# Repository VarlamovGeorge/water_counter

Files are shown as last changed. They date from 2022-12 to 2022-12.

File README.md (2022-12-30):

# IoT-проект для работы с домашними счетчиками воды
Репозиторий представляет собой решение для организации сбора и хранения статистики потребления воды в квартире.

Больше не нужно переживать о том, что вы забудете передать показания воды вовремя. Не нужно каждый месяц лезть в под раковину или открывать технический лючок в санузле. Telgram бот сам напомнит про передачу показаний - пришлет вам актуальное значение счетчиков и даст ссылку на mos.ru. А если захочется провести анализ расхода воды за прошлые периоды - вы сможете сделать это с помощью интерактивных дашбордов прямо в браузере.

<p align="left">
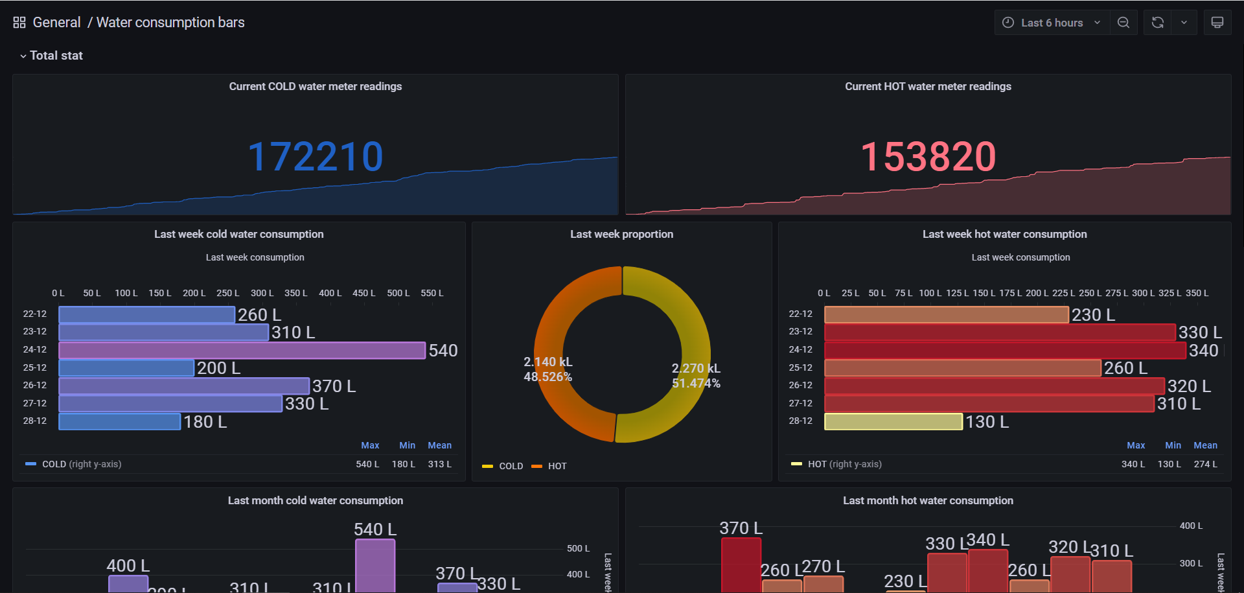
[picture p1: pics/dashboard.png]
  
</p>

## Возможности:
Проект позволяет реализовать следующие возможности для взаимодействия со счетчиками потребления воды:
- сохранение показаний счетчиков в локальную базу данных;
- отображение дашбордов со статистикой потребления;
- взаимодействие с системой через Telegram-бота.

### Telegram-бот
Реализованы следующие возможности бота:
1. Напоминание о необходимости отправки показаний  
Приходит в заранее заданные числа месяца и содержит текущие показания счетчиков, а также ссылку на сайт для передачи показаний (по умолчанию - на портал госуслуг города Москвы mos.ru). У пользователя есть возможность подтвердить отправку (напоминание будет отложено дл следующего месяца) или опровергнуть ее (напоминание будет повторено на следующий день).

2. Получение текущих показаний счетчиков
3. Получение дельты потребления по всем счетчикам за последние 7 и 30 календарных дней

## Требуемое оборудование
1. Raspberry Pi или любой другой компьютер, поддерживающий Python 3, установку Grafana, Mosquitto, Node-RED и SQLite;
1. IoT-микроконтроллер (Wemos D1 mini или любой аналогичный микроконтроллер на основе ESP8266) - по числу счетчиков в квартире;
1. Набор электронных компонент: тактовая кнопка, коннекторы и Breadboard для их подлючения к микроконтроллеру;
1. Водяные счетчики с проводом для подключения к считывающим устройствам.

## Архитектура

<p align="left">
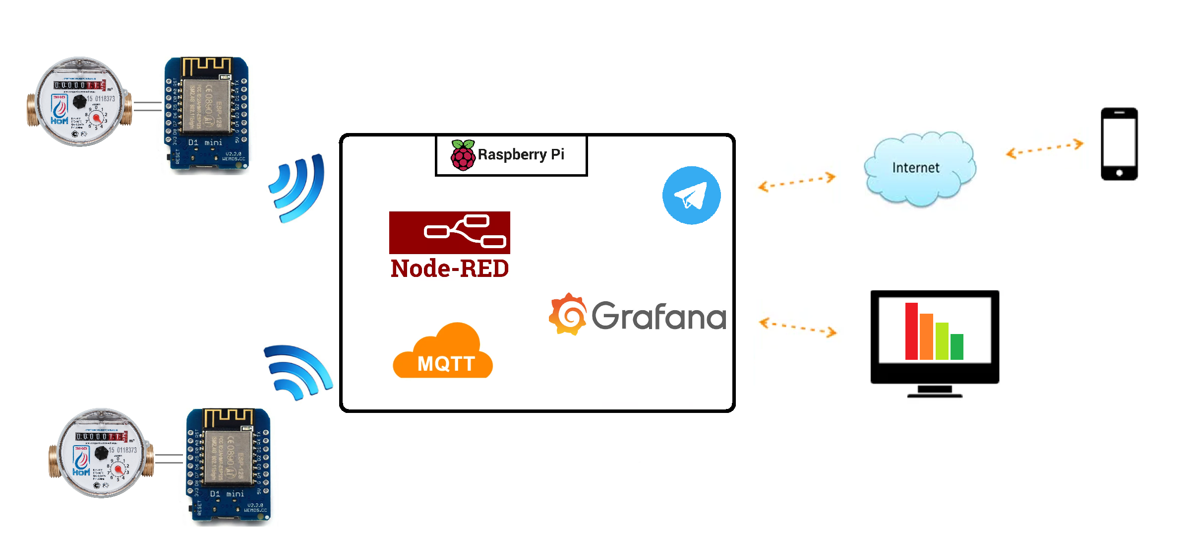
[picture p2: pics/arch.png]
  
</p>
Рядом с каждым счетчиком воды устанавливается IoT-микроконтроллер с WiFi (например - Wemos D1 mini), который подключается к счетчику его родными проводами, после чего с заданной периодичностью рассылает данные о текущих значениях потребления по протоколу MQTT.

Программа микроконтроллера позволяет работать в двух режимах:
1. Основной  
Устройство переходит в режим глубокого сна, и просыпается только для:
- опроса счетчика (по умолчанию - раз в 4-5 секунд)  
При каждом замыкании контактов счетчика текущее показание инкрементируется на 10 литров;
- отправки данных на сервер (по умолчанию - раз в 30 минут)  
Для этого микроконтроллер стартует в качестве клиента, подключающегося к домашней точке доступа Wi-Fi (2,4 ГГц) и рассылающего сообщения в соответствующий MQTT-топик.

2. Настроечный  
Микроконтроллер функционирует в качестве точки доступа Wi-Fi (2,4 ГГц), после подключения к которой пользователю становится доступна web-страница настроек.

В периметре квартиры (дома) поднимается Linux-сервер, с установленной БД и MQTT-брокером сообщений. Сервер подписывается на MQTT-сообщения в топиках для соответствующих счетчиков (для удобства настройки используется Node-RED) и складывает получаемые показания в локальную БД. На том же сервере развернута Grafana для визуализации статистики, а также работает Python-скрипт, отвечающий за Telegram-бота.

### Схема подключения Wemos D1 mini:
<p align="left">
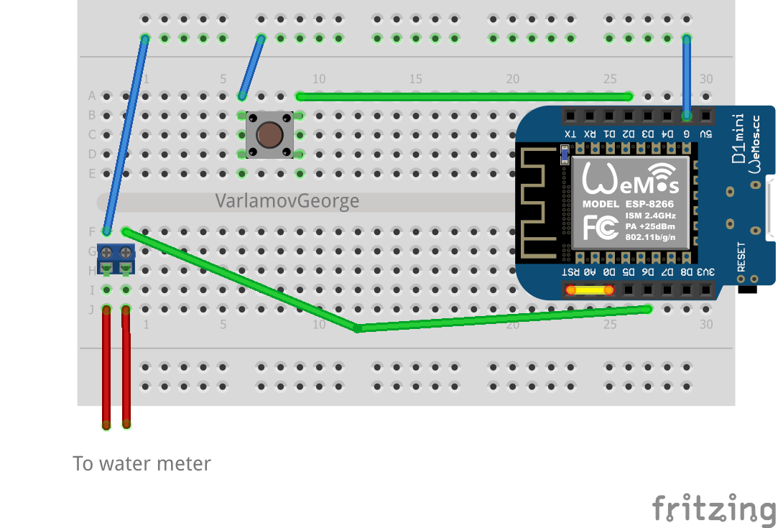
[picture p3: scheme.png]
  
</p>

### Счетчики
Допускается использование счетчиков с количеством разрядов не более 8 (обычно самый младший разряд отвечает за единицы литров, но это не является обязательным условием). Подключать счетчики к системе необходимо проводами, которые замыкаются каждые N литров (например для VLF-R счетчиков такими проводами являются красный и белый, замыкание происходит каждые 10 литров. Для прочих счетчиков - см. инструкцию производителя).

### Подготовка к прошивке микроконтроллера
Перед заливкой скетча в микроконтроллер в параметре WATER_CODE необходимо указать корректное значение типа воды (1 - холодная, 2 - горячая). А также, при желании, указать свои имена MQTT-топиков. По умолчанию используются:
- WATER_COLD и WATER_HOT - для передачи показаний;
- WATER_COLD/CMD и WATER_HOT/CMD - для удаленной корректировки текущего показания, хранящегося в микроконтроллере;
- WATER_COLD/FEEDBACK и WATER_HOT/FEEDBACK - для получения подтверждений о приеме микроконтроллером скорректированного показания.

В случае использования Wemos D1 mini перемычка, соединяющую контакты D0 и RST, требуется для пробуждения микроконтроллера для выхода из глубокого сна. При прошивке микроконтроллера данную перемычку необходимо извлечь.

### Добавление текущих показаний и ввод SSID домашней Wi-Fi сети
Перед началом эксплуатации после заливки скетча в микроконтроллер необходимо выполнить следующие шаги для первоначальной настройки:
1. Перевести микроконтроллер в настроченый режим работы  
Для этого необходимо подать питание, одновременно удерживая кнопку.
Если устройство уже подключено к питанию, то для перехода в режим настройки необходимо удерживать кнопку в течение 5-10 секунд. Если все сделано правильно, то в списке доступных точек доступа появится сеть с SSID="WaterCounter".
1. С любого устройства подключиться к созданной на предыдущем шаге точке доступа  
По умолчанию пароль точки доступа отсутствует.
1. Перейти на страницу 192.168.4.1  
Отобразиться страница с настройками IoT-устройства, а также список SSID видимых точек доступа 2,4 ГГц, доступных микроконтроллеру.
1. Ввести SSID и пароль домашней точки доступа Wi-Fi  
Если сеть видима - сначала следует убедиться, что SSID отображается в списке сетей из предыдущео шага инструкции. Именно к этой сети микроконтроллер будет подключаться в основном режиме работы.
1. Указать текущее значение счетчика (в литрах)
1. Нажать кнопку "Submit"  
После чего отключить микроконтроллер от питания и снова включить. Устройство перейдет в основной режим работы.

### Отправка корректирующих значений в микроконтроллер
Если необходимо скорректировать показания счетчика без подключения микроконтроллера к ПК или перехода в настроечный режим, необходимо отправить команду вида "\<type\>|set|\<value\>" в соответствующий MQTT-топик (см. раздел "Прошивка микроконтроллера").

Где:
- \<type\> - значение типа воды (1 - холодная, 2 - горячая),
- \<value\> - новое показание (в литрах).

Микроконтроллер получит корректировку при следующем подключении к MQTT-брокеру (т.е. в рамках процесса отправки данных на сервер). Результат обработки команды микроконтроллером будет направлен в соответствующий MQTT-топик с суффиксом "/FEEDBACK" ((см. раздел "Прошивка микроконтроллера").

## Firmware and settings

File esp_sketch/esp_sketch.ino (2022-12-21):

#include <ESP8266WiFi.h>
#include <WiFiClient.h>
#include <ESP8266WebServer.h>
#include <EEPROM.h>
#include <AsyncMqttClient.h>

// MQTT settings:
#define MQTTServerIP 192, 168, 1, 6
AsyncMqttClient mqttClient;

#define WATER_CODE 1 // 1 - cold, 2 - hot

#if WATER_CODE == 1
#define MQTT_WATER_TOPIC            "WATER_COLD"
#define MQTT_SUBSCR_TOPIC           "WATER_COLD/CMD"
#define MQTT_FEEDBACK_TOPIC         "WATER_COLD/FEEDBACK"
#define MQTT_WATER_LASTWILL_TOPIC   "WATER_COLD/LASTWILL"

#else
#define MQTT_WATER_TOPIC            "WATER_HOT"
#define MQTT_SUBSCR_TOPIC           "WATER_HOT/CMD"
#define MQTT_FEEDBACK_TOPIC         "WATER_HOT/FEEDBACK"
#define MQTT_WATER_LASTWILL_TOPIC   "WATER_HOT/LASTWILL"
#endif

/*
EEPROM scheme:
|--------0-31-------|--------32-63------|------64-67------|
|SSID for home Wi-Fi|PASS for home Wi-Fi|Water meter value|
*/

// Home WiFi settings:
String ssid = "";                   // Home Wi-Fi SSID variable
String password = "";               // Home Wi-Fi PASS variable
const char *ssidAP = "WaterCounter";// Wi-Fi SSID for ESP access point
const char *passwordAP = "";        // Wi-Fi PASS for ESP access point
const int WiFiTimeoutSec = 60;      // Wi-Fi connection timeout (seconds)
const int MQTTTimeoutSec = 20;      // MQTT connection timeout (seconds)
ESP8266WebServer server(80);
WiFiClient  client;

// Deep sleep duration (seconds):
const int sleepTimeS = 5;
// MQTT publication frequency (seconds):
#define SENDSEC 1800 // 1800 seconds = half an hour, 86400 seconds = 24 hours
// EEPROM rewrite frequency (seconds):
#define EEWRITESEC 120960 // 120960 seconds = 14 days

// Pin assignment:
#define BUTTON_PIN 4     // GPIO4 for change-mode button
#define WATER_PIN 12 // GPIO12 for water meter

// RTC memory addresses (persistently stored while deep sleep):
#define COUNT_STEP_ADDR 64      // Steps count for measure how much time has passed
#define PREV_WATER_STATE_ADDR 65 // Previous step water meter state (close or open)
#define WATER_VAL_ADDR 67       // Actual water meter indication (1 block of 4 bytes)
#define WATER_OLD_VAL_ADDR 69   // Previous water meter indication (1 block of 4 bytes)

// ADC_MODE(ADC_VCC); // Use if you want to use batteries

// Other variables:
boolean loadState = true; // Boot load mode: true - main (count) mode; false - Wi-Fi AP mode for configuring)
int countStep;

// Additional RTC intended library:
extern "C" {
  #include "user_interface.h"
}

// User struct to store water meters indications (2 blocks of 4 bytes):
typedef struct {
  long waterVal;
} rtcStore;

rtcStore rtcMem; // Struct to store current measurements
rtcStore rtcMemPrev; // Struct to store current previous loaded into RTC measurements

// Auxiliary arrays:
int waterByte[4];

//---------------------------------------------------------------------------------------------
//---------------------------------MQTT handlers:----------------------------------------------
void onMqttConnect(bool sessionPresent) { // MQTT connect handler
  Serial.println("Connected to the MQTT broker");
  mqttClient.subscribe(MQTT_SUBSCR_TOPIC, 1); // Subscribtion on topic with adjusting values from user
  Serial.print("Subscription topic: ");
  Serial.println(MQTT_SUBSCR_TOPIC);
}

void onMqttDisconnect(AsyncMqttClientDisconnectReason reason) {// MQTT disconnect handler
  Serial.println("Disconnected from the broker");
  // Serial.println("Reconnecting to MQTT broker...");
  // mqttClient.connect();
}

void onMqttSubscribe(uint16_t packetId, uint8_t qos) {// MQTT subscription handler
  Serial.print("Subscribe acknowledged");
  Serial.print(" packetId: ");
  Serial.print(packetId);
  Serial.print(" qos: ");
  Serial.println(qos);
}
/*
void onMqttUnsubscribe(uint16_t packetId) {// MQTT unsubscription handler
  Serial.println("** Unsubscribe acknowledged **");
  Serial.print("  packetId: ");
  Serial.println(packetId);
}
*/

// MQTT get message handler:
void onMqttMessage(char* topic, char* payload, AsyncMqttClientMessageProperties properties, size_t len, size_t index, size_t total) {
  String feedbackMessage = "";
  Serial.println("MATT message received");
  Serial.println("topic: "+String(topic)+"; qos: "+String(properties.qos)+"; dup: "+String(properties.dup)+"; retain: "+String(properties.retain)+"; len: "+String(len)+"; index: "+String(index));
  Serial.println("Payload: "+String(payload));

  int waterByteVals[4];
  int cmd_water_type = String(payload).substring(0, String(payload).indexOf("|")).toInt(); // Water type placed before first "|" (1 - cold, 2 - hot)
  String cmd_water_commmand = String(payload).substring(2, String(payload).indexOf("|", 3)); // Command type placed before second "|"
  String cmd_water_value = String(payload).substring(3+cmd_water_commmand.length(), String(payload).length()); // New water meter value from user
  Serial.println("Received water: "+String(cmd_water_type));
  Serial.println("Received comand: "+String(cmd_water_commmand));
  Serial.println("Received value: "+String(cmd_water_value));
  if (cmd_water_type==WATER_CODE){ // Check if command assumes correct water meter type
    if (cmd_water_commmand=="set"){
      rtcMem.waterVal = cmd_water_value.toInt();
      feedbackMessage = "Current water meter value updated: " + String(rtcMem.waterVal);
    }
    else {
      feedbackMessage = "Wrong command received. List of allowed commands: ['set']";
    }
  }
  
  else {
    feedbackMessage = "Wrong command received: " + String(payload) + " 'N|CMD|VALUE' message expected...";
  }
  Serial.println(feedbackMessage);
  mqttClient.publish(MQTT_FEEDBACK_TOPIC, 1, false, feedbackMessage.c_str());
  /*if (strcmp(topic, MQTT_SUBSCR_TOPIC) == 0)  {
    //setRelay(payload);
    mqttClient.publish(MQTT_FEEDBACK_TOPIC, 1, false, payload);
    Serial.println("Publishing Feedback");
  }*/
}

void onMqttPublish(uint16_t packetId) {// MQTT publish handler
  Serial.print("Published");
  Serial.print("  packetId: ");
  Serial.print(packetId);
  Serial.print("\n\n");
}
//---------------------------------------------------------------------------------------------
//---------------------------------------------------------------------------------------------


void setup()
{
  Serial.begin(115200);
    EEPROM.begin(512);
  // Seting all pins as inputs:
  pinMode(BUTTON_PIN, INPUT_PULLUP);
  pinMode(WATER_PIN, INPUT_PULLUP);
  // Getting operating mode:
  loadState = digitalRead(BUTTON_PIN); // Pressed = volage low level
  Serial.println("\nIs MODE button pressed? " + String(!loadState));
  WiFi.mode(WIFI_AP_STA);// ESP in "station + access point" mode

  //----------MAIN (COUNTER) MODE-------------------------------------------------------------
  if (loadState) { // Button released
    Serial.println("\nESP8266 in MAIN mode!");
    // Readig previous measures from RTC and storing them into rtcMem variable:
    system_rtc_mem_read(WATER_VAL_ADDR, &rtcMem, 4);
    system_rtc_mem_read(WATER_OLD_VAL_ADDR, &rtcMemPrev, 4);
    system_rtc_mem_read(COUNT_STEP_ADDR, &countStep, 4);
    // If step number bigger then (EEWRITESEC/sleepTimeS) or less then 0 - resetting step number:
    if (countStep > (EEWRITESEC / sleepTimeS) || countStep < 0) {
      countStep = 0;
      for (int i = 0; i < 4; ++i) // Getting measurements from EEPROM (byte by byte)
      {
        waterByte[i] = EEPROM.read(64 + i);
      }
      // Translating the meter values into numerical form into rtcMem:
      rtcMem.waterVal = waterByte[0] + 100 * waterByte[1] + 10000 * waterByte[2] + 1000000 * waterByte[3];
      Serial.println("Consumption value is extracted from EEPROM: " + String(rtcMem.waterVal));
    }
    else {
      // Increasing step number:
      countStep += 1;
    }
    // Checking if water meter pins state changed:
    if (checkWaterCounter(WATER_PIN, PREV_WATER_STATE_ADDR)) { //Состояние счетчика холодной воды изменилось = истрачено еще 10 л
      rtcMem.waterVal += 10; // 10 litters more on consumption
    }

    // Writing all info into Serial:
    Serial.println("Step number: " + String(countStep) + "\tConsumption: " + String(rtcMem.waterVal));
    Serial.println("Old values from RTC: " + String(rtcMemPrev.waterVal));
    
    // SENDSEC seconds (equals SENDSEC/sleepTimeS steps) passed - publishing data on MQTT:
    if (countStep % (SENDSEC / sleepTimeS) == 0) {
      // Getting params from EEPROM on first run:
      for (int i = 0; i < 32; ++i) // Getting home Wi-Fi SSID and PASS
      {
        ssid += char(EEPROM.read(i));
        password += char(EEPROM.read(32 + i));
      }
      // Connectig to Wi-Fi:
      Serial.println("Trying to connect to Wi-Fi...");
      Serial.println("SSID: "+ String(ssid.c_str())+"; PASS: "+ String(password.c_str()));
      
      WiFi.begin(ssid.c_str(), password.c_str());
      int c = 0;
      while (c < (WiFiTimeoutSec * 2) && WiFi.status() != WL_CONNECTED) {
        delay(500);
        Serial.print(".");
        c++;
      }
      if (WiFi.status() == WL_CONNECTED) {
        Serial.println("");
        Serial.println("WiFi connected");
        // Showing IP-address in Serial:
        Serial.println(WiFi.localIP());

        // MQTT preparations:
        mqttClient.onConnect(onMqttConnect);
        mqttClient.onDisconnect(onMqttDisconnect);
        mqttClient.onSubscribe(onMqttSubscribe);
        // mqttClient.onUnsubscribe(onMqttUnsubscribe);
        mqttClient.onMessage(onMqttMessage);
        mqttClient.onPublish(onMqttPublish);
        mqttClient.setServer(IPAddress(MQTTServerIP), 1883);
        // mqttClient.setKeepAlive(5).setCleanSession(false).setWill(MQTT_WATER_LASTWILL_TOPIC, 2, true, "Device is offline").setCredentials("username", "password").setClientId("m");
        mqttClient.setKeepAlive(5).setCleanSession(false);
        Serial.println("Connecting to MQTT...");
        Serial.println(IPAddress(MQTTServerIP));
        mqttClient.connect();
        int c = 0;
        while (c < (MQTTTimeoutSec * 2) && mqttClient.connected() != true) {
          delay(500);
          Serial.print(".");
          c++;
        }
        // float extVCC = ESP.getVcc(); // Getting supply battery voltage
        // String payload = String(rtcMem.waterVal)+";"+String(extVCC);
        String payload = String(rtcMem.waterVal); // Payload string for publishing
        
        // Publishing data on MQTT:
        mqttClient.publish(MQTT_WATER_TOPIC, 1, false, payload.c_str());
        Serial.println("Data sent to MQTT server: "+ payload);
        delay(1000);
        // Storing sent values into rtcMemPrev (as previous measurements):
        rtcMemPrev.waterVal = rtcMem.waterVal;
      }
      else {
        Serial.println("\nWi-Fi connection failed!.. Try to use another SSID.");
      }
    }
    // EEWRITESEC seconds (equals EEWRITESEC/sleepTimeS steps) passed - saving data into EEPROM:
    if (countStep >= (EEWRITESEC/sleepTimeS)) {
      int waterByteVals[4];
      // Splitting values on bytes:
      for (int i = 0; i < 4; ++i) {
        waterByteVals[i] = (rtcMem.waterVal / int(pow(10, i * 2))) % 100; //[0]-два последних разряда, [3]-два первых разряда
      }
      ClearEeprom(64, 128); // Deleting old data from EEPROM
      delay(10);
      for (int i = 0; i < 4; ++i) {
        EEPROM.write(64 + i, waterByteVals[i]);
      }
      EEPROM.commit();
      Serial.println("Added consumption to EEPROM: " + String(rtcMem.waterVal));
      countStep = 0; // Resetting step number
    }

    // Writing data into RTC memory:
    Serial.println("Writings measures to RTC: " + String(rtcMem.waterVal));
    system_rtc_mem_write(COUNT_STEP_ADDR, &countStep, 4); // Step number
    system_rtc_mem_write(WATER_VAL_ADDR, &rtcMem, 4); // Water meters measurements
    system_rtc_mem_write(WATER_OLD_VAL_ADDR, &rtcMemPrev, 4); // Previous water meters measurements

    // All done - going to deep sleep:
    Serial.println("ESP8266 in sleep mode");
    ESP.deepSleep(sleepTimeS * 1000000);
  }

  //----------ALTERNATIVE MODE (Wi-Fi access point) MODE-------------------------------------------------------------
  else { // Button pressed
    Serial.println("\nESP8266 in ALTERNATIVE mode!!! \n Creating Access Point:");
    Serial.println("Starting AP mode. SSID=");
    Serial.println(ssidAP);
    Serial.println("PASSWORD=");
    Serial.println(passwordAP);
    // Reading last saved in RTC values to show on web page:
    system_rtc_mem_read(WATER_VAL_ADDR, &rtcMem, 4);
    // If shit in data - getting values from EEPROM (can be on the first run):
    if (rtcMem.waterVal > 99999999 || rtcMem.waterVal < 0) {
      for (int i = 0; i < 4; ++i) // Reafding EEPROM values (byte by byte)
      {
        waterByte[i] = EEPROM.read(64 + i);
      }
      // Translating the meter values into numerical form into rtcMem:
      rtcMem.waterVal = waterByte[0] + 100 * waterByte[1] + 10000 * waterByte[2] + 1000000 * waterByte[3];
    }
    // Reading Wi-Fi settings saved in EEPROM to show on web page:
    for (int i = 0; i < 32; ++i) // Getting home Wi-Fi SSID and PASS
    {
      ssid += char(EEPROM.read(i));
      password += char(EEPROM.read(32 + i));
    }
    // Creating access point with params stored in sketch:
    WiFi.softAP(ssidAP, passwordAP);
    delay(10);
    server.on("/", D_AP_SER_Page); // Main HTML-page URL
    server.on("/a", Get_Req);      // URL for page after "Submit" button selection
    server.begin();
    delay(300);
  }
}
//********************************END SETUP BLOCK***********************


// Function for checking if water meter contacts stage has changed:
bool checkWaterCounter(int gpioIn, int countAddrBool) { //Input pin number; RTC memory address with water meter state
  bool isChanged;
  int oldVal, curVal;
  // Getting previos state stored in RTC memory:
  system_rtc_mem_read(countAddrBool, &oldVal, 4);
  curVal = digitalRead(gpioIn); // Current water meter state

  if (curVal == 0 && oldVal == 1) {
    isChanged = true;
  }
  else {
    isChanged = false;
  }
  //Serial.println("GPIO: " + String(gpioIn) + "\toldVal: " + String(oldVal) + "\tcurVal: " + String(curVal) + "\tisChanged: " + String(isChanged));
  
  // Update state in RTC memory:
  system_rtc_mem_write(countAddrBool, &curVal, 4);
  return isChanged;
}

// Function for creating web page for access point:
void D_AP_SER_Page() {
  int Tnetwork = 0, i = 0, len = 0;
  String st = "", s = "";         // String array to store the SSID's of available networks
  Tnetwork = WiFi.scanNetworks(); // Scan for all available Wi-Fi networks
  st = "<ul>";
  for (int i = 0; i < Tnetwork; ++i)
  {
    // Print SSID and RSSI for each network found
    st += "<li>";
    st += i + 1;
    st += ": ";
    st += WiFi.SSID(i);
    st += " (";
    st += WiFi.RSSI(i);
    st += ")";
    st += (WiFi.encryptionType(i) == ENC_TYPE_NONE) ? " " : "*";
    st += "</li>";
  }
  st += "</ul>";
  IPAddress ip = WiFi.softAPIP(); //Getting ESP IP-address
  s = "\n\r\n<!DOCTYPE HTML>\r\n<html><h1>Настройки системы удаленного контроля счетчиков</h1> ";
  s += "\r\n<head>\r\n<meta http-equiv=\"Content-Type\" content=\"text/html; charset=utf-8\">\r\n</head>\r\n";
  s += "<p>";
  s += st;
  s += "<p>";
  s += "Текущие настройки Wi-Fi: SSID=" + String(ssid);
  s += " Password=" + String(password);
  s += "<p>";
  s += "<p>";
  s += "Данные отправляются в MQTT каждые " + String(SENDSEC) + " секунд.";
  s += "<p>";
  s += "Текущие значения счетчиков: ХОЛОДНАЯ ВОДА=" + String(rtcMem.waterVal);
  s += "<p>";
  s += "Имя топика MQTT с даннными: ";
  s += MQTT_WATER_TOPIC;
  s += ". Имя топика MQTT для правки значений: ";
  s += MQTT_SUBSCR_TOPIC;
  s += ". Имя топика MQTT с подтверждениями от ESP: ";
  s += MQTT_FEEDBACK_TOPIC;
  s += ". Формат данных: '123456'.";
  s += "<form method='get' action='a'><label>SSID: </label><input name='ssid' length=32><label>Pasword: </label><input name='pass' length=32><br />";
  s += "<label>Water: </label><input name='waterInit' length=8><br /><input type='submit'>";
  s += "</form>";
  s += "</html>\r\n\r\n";

  server.send( 200 , "text/html", s);
}

// Function for submit data from HTML web page:
void Get_Req() {
  String sssid = ""; // SSID variable
  String passs = ""; // PASS variable

  if (server.hasArg("ssid") && server.hasArg("pass")) {
    sssid = server.arg("ssid"); // Getting SSID from web form
    passs = server.arg("pass"); // Getting PASS from web form
    Serial.println("Wi-Fi settigns from web-page: " + String(sssid) + "; " + String(passs));
  }

  String waterInit = ""; // Current water consumption variable
  int waterInitInt; // Current water consumption variable (integer)
  int waterByteVals[4];

  if (server.hasArg("waterInit")) {
    waterInit = server.arg("waterInit"); // Getting value from web page
    // Transforming into integer:
    waterInitInt = waterInit.toInt();
    Serial.println("Water measures from web-page: "+String(waterInitInt));
    //Разбиваем 8-значное число на 4 байта:
    for (int i = 0; i < 4; ++i) {
      waterByteVals[i] = (waterInitInt / int(pow(10, i * 2))) % 100;
    }
  }

  if (sssid.length() > 1 && passs.length() > 1) {
    ClearEeprom(0, 64); // Deleting old SSID and PASS values from EEPROM
    delay(10);
    // Storing new SSID and PASS from web page:
    for (int i = 0; i < sssid.length(); ++i)
    {
      EEPROM.write(i, sssid[i]);
    }
    for (int i = 0; i < passs.length(); ++i)
    {
      EEPROM.write(32 + i, passs[i]);
    }
    EEPROM.commit();
    Serial.println("Added to EEPROM: SSID=" + sssid + "; Pass=" + passs);
  }

  // Storing new water consuption values from web page:
  if (waterInit.length() > 1) {
    ClearEeprom(64, 128); // Deleting old measures from EEPROM
    delay(10);
    for (int i = 0; i < 4; ++i)
    {
      EEPROM.write(64 + i, waterByteVals[i]);
    }
    EEPROM.commit();
    delay(10);
    Serial.println("Consumption=" + String(waterByteVals[0] + 100 * waterByteVals[1] + 10000 * waterByteVals[2] + 1000000 * waterByteVals[3]));
    // Resetting step number:
    countStep = 0;
    system_rtc_mem_write(COUNT_STEP_ADDR, &countStep, 4); // Step number
    delay(100);

    // Checking that everything was saved correctly:
    for (int i = 0; i < 4; ++i) // Raading EEPROM byte by byte
      {
        waterByte[i] = EEPROM.read(64 + i);
      }
      //Переводим показания счетчиков в числовой вид и выводим в Serial:
      int a = waterByte[0] + 100 * waterByte[1] + 10000 * waterByte[2] + 1000000 * waterByte[3];
      Serial.println("Consumption value is extracted from EEPROM: " + String(a));
  }


  String s = "\r\n\r\n<!DOCTYPE HTML>\r\n<html>";
  s += "\r\n<head>\r\n<meta http-equiv=\"Content-Type\" content=\"text/html; charset=utf-8\">\r\n<!head>\r\n";
  s += "\r\n<h1>Настройки загружены!</h1>";
  s += "<p>Данные успешно сохранены! Для штатной работы выключите и включите систему или просто нажмите кнопку RESET.</html>\r\n\r\n";
  server.send(200, "text/html", s);
}

// Function that cleans EEPROM:
void ClearEeprom(int startByte, int endByte) {
  Serial.println("Clearing EEPROM from " + String(startByte) + " to " + String(endByte));
  for (int i = startByte; i < endByte; ++i) {
    EEPROM.write(i, 0);
  }
}

void loop() // For operating in alternative mode
{
  server.handleClient();
}

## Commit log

2022-12-21 Added mqtt Arduino library
2022-12-21 Added fritzing scheme
    [scheme.fzz]
2022-12-23 Node-RED flow added
